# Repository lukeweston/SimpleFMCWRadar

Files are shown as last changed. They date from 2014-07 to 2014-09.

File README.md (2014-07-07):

This relatively compact, cheap, simple FMCW radar operates in the spectrum around 5.8-6.0 GHz and is aimed at lowering the barrier to entry for experiments with radar and general education around RF and microwave electronics. It is capable of speed measurement,
rangefinding and SAR imaging (with appropriate moving antennas or a moving vehicle.) It is potentially applicable to experiments with autonomous aircraft (or spacecraft) altitude-finding, SAR imaging/mapping or navigation as an alternative to (or in addition to)
other sensing techniques such as GPS, ultrasonics, LIDAR or barometry, without some of the limitations applicable to those technologies.

This is still an early prototype, a rough quick work that is still very much in progress and evolving as bits are designed and built and redesigned.

Frequency-modulated RF is generated by the HMC431 VCO, at about 5.8-6.0 GHz, amplified by a HMC476 MMIC gain block, and split in half by the Wilkinson divider. Half the RF output from the divider is amplified again and sent to the transmit antenna connector.
The local oscillator, from the other side of the splitter, is amplified again and applied to the LO port of the HMC219 double-balanced mixer. The reflected RF from the receive antenna comes in to the HMC717 6 GHz LNA where it is amplified, and the amplified output is
fed into the mixer.

A couple of pi attenuators are used, after the VCO, before the mixer LO port and after the mixer's IF output, to "tune" optimal mixer LO level and overall performance. Although I haven't fixed certain values for these attenuators yet, space for them is left on
the board.

IF filtering, amplification and signal processing, along with generation of the 0-10V modulation signal for the VCO, are done on a separate board.

Source files - EDA/CAD information: These are CadSoft EAGLE files. See www.cadsoftusa.com/ for download and licensing information. The "free as in beer" "light" Eagle license is perfectly capable of opening and editing these files - the boards are only two-layer and
are relatively small. A PDF schematic is provided along with industry-standard fabrication-ready RS274X (Gerber) files.

License information: Open Hardware as per the CERN Open Hardware License; please see license.txt

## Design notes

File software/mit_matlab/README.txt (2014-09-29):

NOTE:
These MATLAB files are, at this stage, simply "forked" from the public files provided by Greg Charvat and his MIT/Lincoln Lab group.

You may find the original MATLAB signal-processing scripts and other documentation here:

http://ocw.mit.edu/resources/res-ll-003-build-a-small-radar-system-capable-of-sensing-range-doppler-and-synthetic-aperture-radar-imaging-january-iap-2011/projects/

All credit, ownership, IP rights, license terms and so forth belong to Greg Charvat - not me!

I am currently working on making some tweaks and changes to acheive the following goals:

- Adaptations to suit the centre frequency, sweep bandwidth and modulation rate of my radar electronics

- Avoid the use of expensive commercial software like MATLAB, and adapt the code for signal processing of the audio samples such that
the same results can be had without proprietary software.

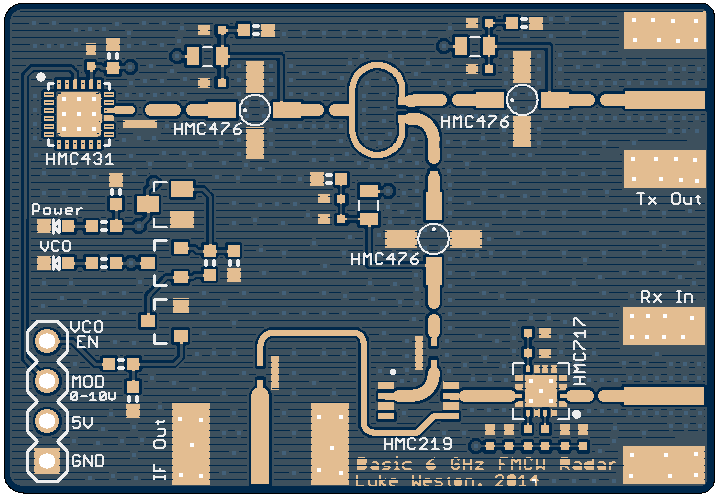
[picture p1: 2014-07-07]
photos/RFboard-preview.png

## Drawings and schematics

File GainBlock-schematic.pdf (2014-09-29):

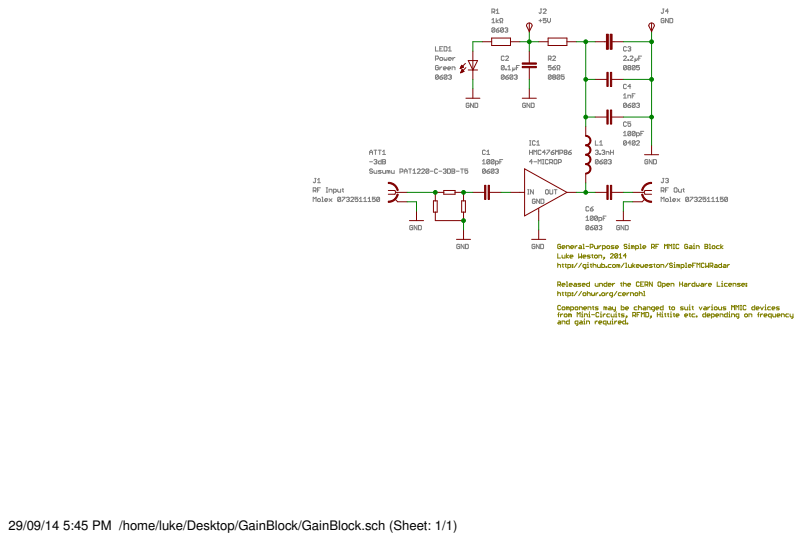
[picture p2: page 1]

29/09/14 5:45 PM /home/luke/Desktop/GainBlock/GainBlock.sch (Sheet: 1/1)

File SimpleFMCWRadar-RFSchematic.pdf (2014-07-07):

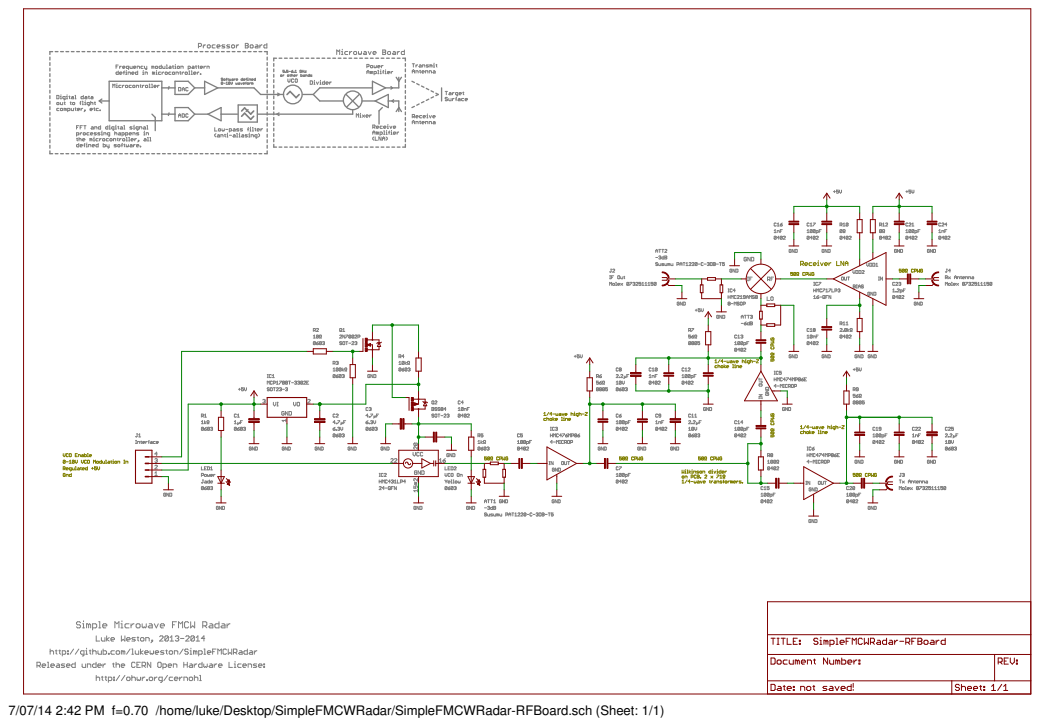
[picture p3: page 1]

7/07/14 2:42 PM f=0.70 /home/luke/Desktop/SimpleFMCWRadar/SimpleFMCWRadar-RFBoard.sch (Sheet: 1/1)

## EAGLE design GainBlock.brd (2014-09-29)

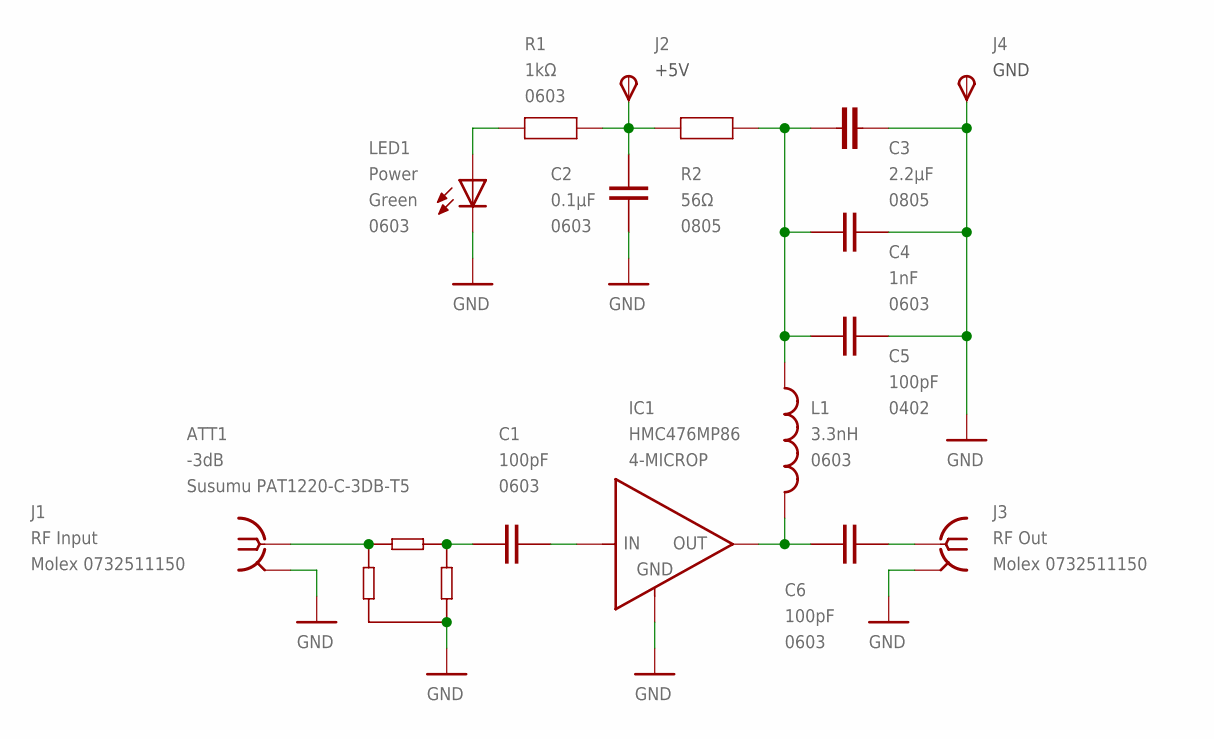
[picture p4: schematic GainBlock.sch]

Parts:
ATT1: -3dB; PAT1220
C1, C6: 100pF; 0603
C2: 0.1µF; 0603
C3: 2.2µF; 0805; VOLTAGE 10V
C4: 1nF; 0603
C5: 100pF; 0402
IC1: HMC476MP86; WW107
J1: RF Input; J502-ND-142-0701-881/886; MPN 142-0701-881
J2, J4: TPSPAD1-13; P1-13
J3: RF Out; J502-ND-142-0701-881/886; MPN 142-0701-881
L1: 3.3nH; 0603
LED1: Power; LED-0603
R1: 1kΩ; 0603
R2: 56Ω; 0805

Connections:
GND: ATT1.3, C2.2, C3.1, C4.2, C5.2, IC1.2 (GND), IC1.4 (GND), J1.G@1 (GND), J1.G@2 (GND), J1.G@3 (GND), J1.G@4 (GND), J3.G@1 (GND), J3.G@2 (GND), J3.G@3 (GND), J3.G@4 (GND), J4.TP, LED1.C
unnamed: ATT1.1, J1.1
unnamed: ATT1.2, C1.1
unnamed: LED1.A, R1.1
unnamed: C6.2, J3.1
unnamed: C1.2, IC1.1 (IN)
unnamed: C6.1, IC1.3 (OUT), L1.2
unnamed: C3.2, C4.1, C5.1, L1.1, R2.1
unnamed: C2.1, J2.TP, R1.2, R2.2

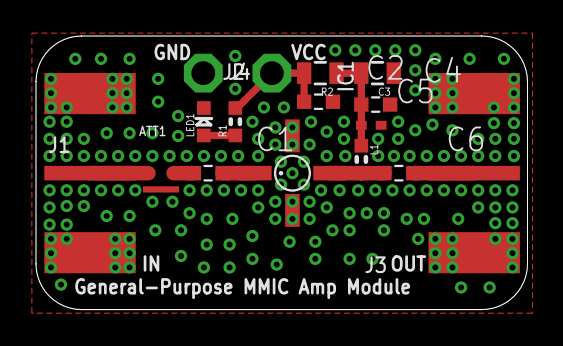
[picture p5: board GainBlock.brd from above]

Board: 2 copper layers, 27.3 x 15.2 mm, 16 parts (0 on the bottom side), 9 nets.

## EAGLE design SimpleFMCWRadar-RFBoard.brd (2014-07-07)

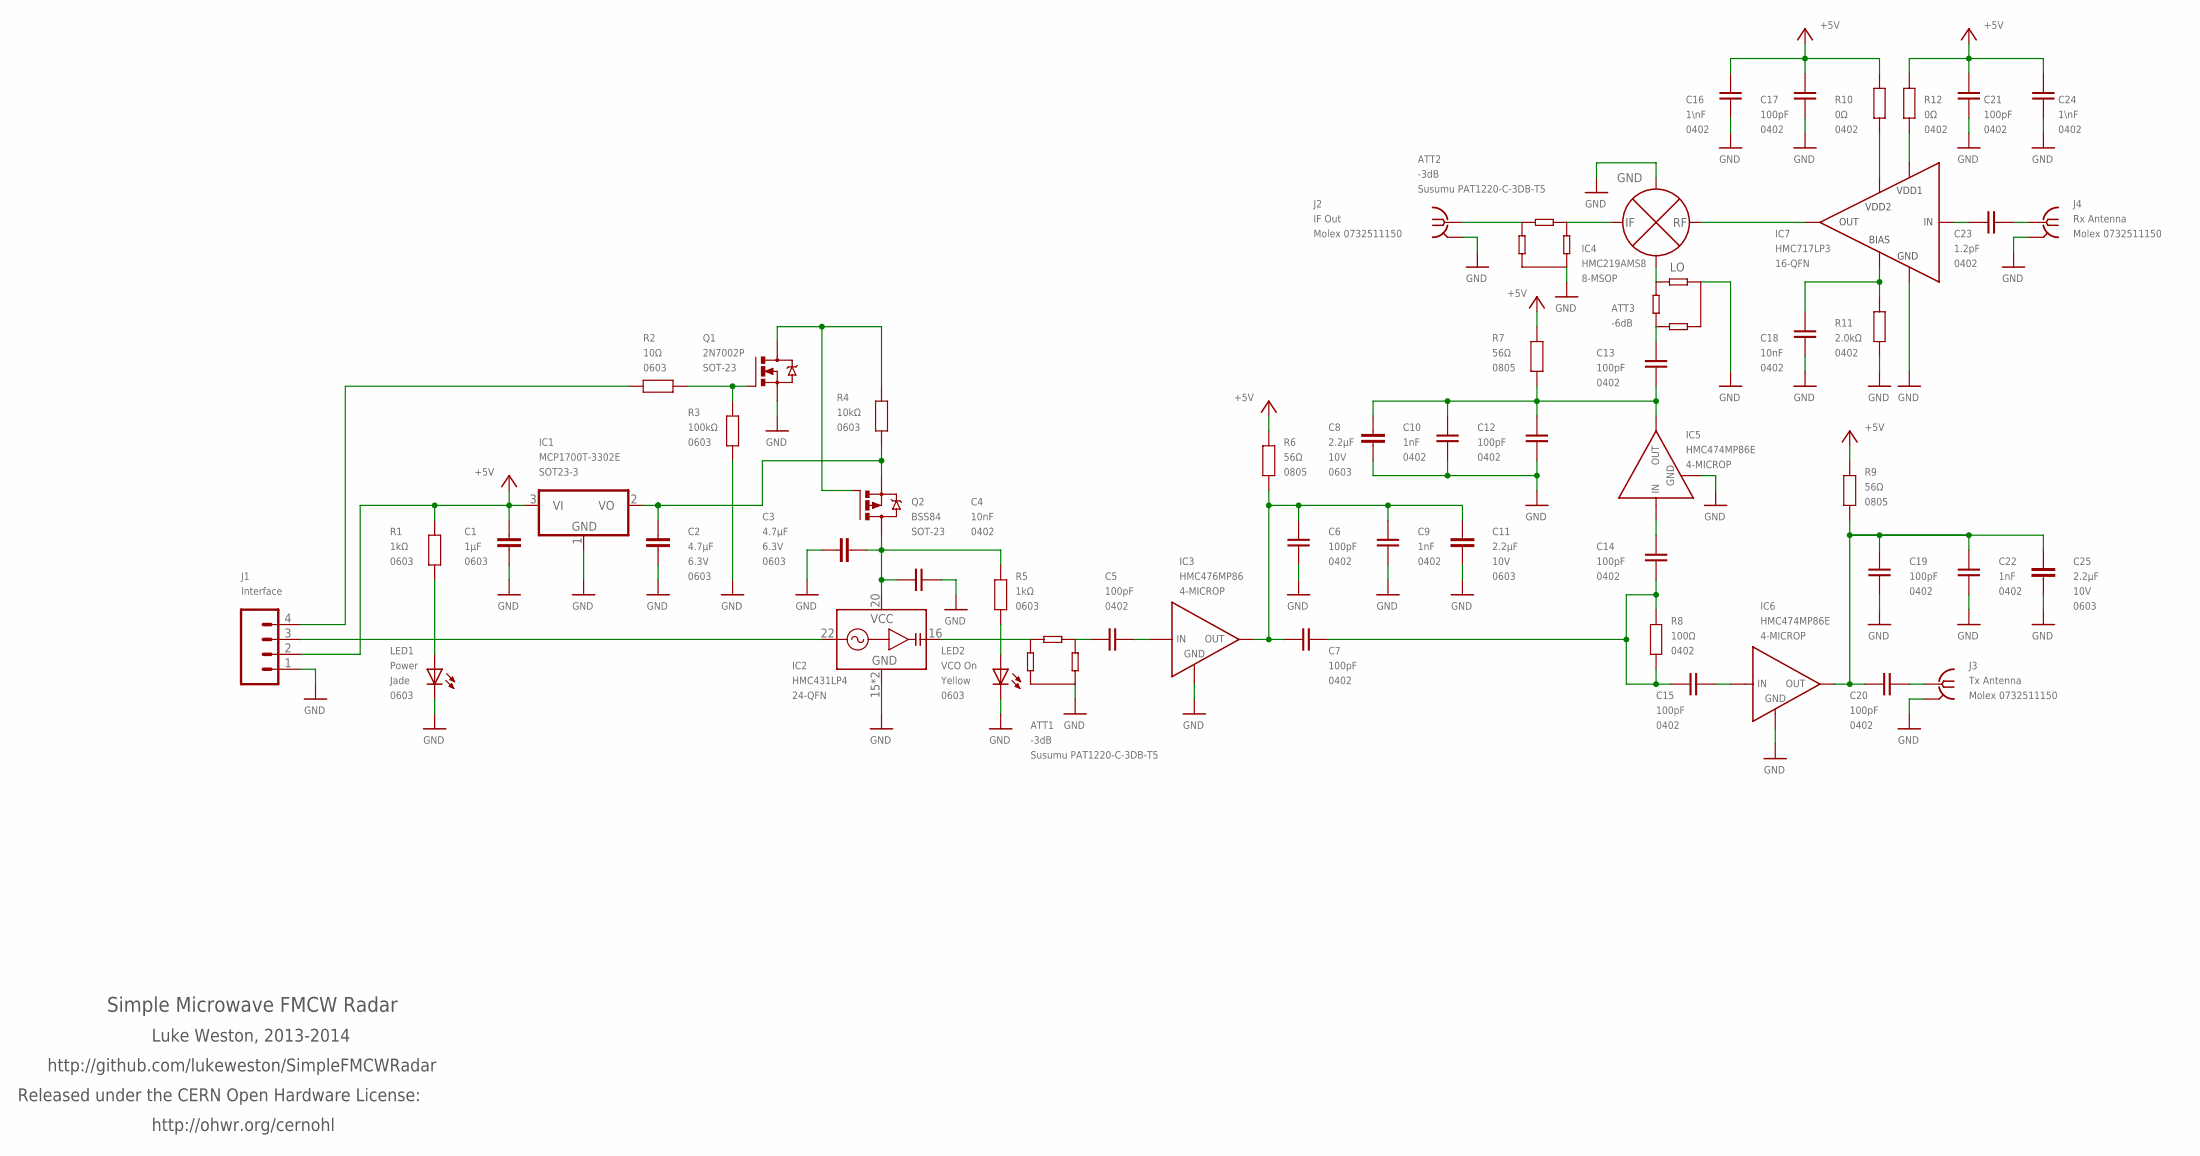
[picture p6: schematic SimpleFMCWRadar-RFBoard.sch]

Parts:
ATT1, ATT2: -3dB; PAT1220
ATT3: -6dB; PAT1220
C1: 1µF; 0603
C2, C3: 4.7µF; 0603; VOLTAGE 6.3V
C4, C18: 10nF; 0402
C5, C6, C7, C12, C13, C14, C15, C17, C19, C20, C21: 100pF; 0402
C8, C11, C25: 2.2µF; 0603; VOLTAGE 10V
C9, C10, C22: 1nF; 0402
C16, C24: 1\nF; 0402
C23: 1.2pF; 0402
IC1: MCP1700T-3302E; SOT23
IC2: HMC431LP4; QFN24
IC3: HMC476MP86; WW107
IC4: HMC219AMS8; 8-MSOP
IC5, IC6: HMC474MP86E; WW107
IC7: HMC717LP3; 16-QFN
J1: Interface; 1X04
J2: IF Out; J502-ND-142-0701-881/886; MPN 142-0701-881
J3: Tx Antenna; J502-ND-142-0701-881/886
J4: Rx Antenna; J502-ND-142-0701-881/886
LED1: Power; LED-0603
LED2: VCO On; LED-0603
Q1: 2N7002P; SOT23-3
Q2: BSS84; SOT23-3
R1, R5: 1kΩ; 0603
R2: 10Ω; 0603
R3: 100kΩ; 0603
R4: 10kΩ; 0603
R6, R7, R9: 56Ω; 0805
R8: 100Ω; 0402
R10, R12: 0Ω; 0402
R11: 2.0kΩ; 0402

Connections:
+5V: C1.2, C16.2, C17.2, C21.2, C24.2, IC1.3 (VI), J1.2, R1.2, R6.2, R7.1, R9.1, R10.2, R12.2
GND: ATT1.3, ATT2.3, ATT3.3, C1.1, C2.2, C3.2, C4.2, C6.1, C8.1, C9.1, C10.1, C11.1, C12.1, C16.1, C17.1, C18.1, C19.2, C21.1, C22.2, C24.1, C25.1, IC1.1 (GND), IC2.15 (GND), IC2.EXP (GND), IC3.2 (GND), IC3.4 (GND), IC4.1 (GND), IC4.3 (GND), IC4.6 (GND), IC4.8 (GND), IC5.2 (GND), IC5.4 (GND), IC6.2 (GND), IC6.4 (GND), IC7.P$1 (GND), IC7.P$3 (GND), IC7.P$4 (GND), IC7.P$5 (GND), IC7.P$6 (GND), IC7.P$7 (GND), IC7.P$9 (GND), IC7.P$10 (GND), IC7.P$12 (GND), IC7.P$14 (GND), IC7.P$16 (GND), IC7.PAD (GND), J1.1, J2.G@1 (GND), J2.G@2 (GND), J2.G@3 (GND), J2.G@4 (GND), J3.G@1 (GND), J3.G@2 (GND), J3.G@3 (GND), J3.G@4 (GND), J4.G@1 (GND), J4.G@2 (GND), J4.G@3 (GND), J4.G@4 (GND), LED1.C, LED2.C, Q1.2 (S), R3.1, R11.1
unnamed: C5.2, IC3.1 (IN)
unnamed: C6.2, C7.1, C9.2, C11.2, IC3.3 (OUT), R6.1
unnamed: ATT1.2, C5.1
unnamed: ATT1.1, IC2.16 (RFOUT)
unnamed: IC2.22 (VTUNE), J1.3
unnamed: C15.1, IC6.1 (IN)
unnamed: C7.2, C14.1, C15.2, R8.1, R8.2
unnamed: C20.1, J3.1
unnamed: ATT3.2, IC4.2 (LO)
unnamed: Q1.1 (G), R2.1, R3.2
unnamed: ATT2.2, IC4.5 (IF)
unnamed: C23.2, IC7.P$2 (IN)
unnamed: C23.1, J4.1
unnamed: IC4.7 (RF), IC7.P$11 (OUT)
unnamed: C18.2, IC7.P$8 (BIAS), R11.2
unnamed: IC7.P$13 (VDD2), R10.1
unnamed: IC7.P$15 (VDD1), R12.1
unnamed: LED1.A, R1.1
unnamed: ATT3.1, C13.2
unnamed: C3.1, C4.1, IC2.20 (VCC), Q2.3 (D), R5.2
unnamed: C2.1, IC1.2 (VO), Q2.2 (S), R4.1
unnamed: Q1.3 (D), Q2.1 (G), R4.2
unnamed: J1.4, R2.2
unnamed: C19.1, C20.2, C22.1, C25.2, IC6.3 (OUT), R9.2
unnamed: LED2.A, R5.1
unnamed: C8.2, C10.2, C12.2, C13.1, IC5.3 (OUT), R7.2
unnamed: C14.2, IC5.1 (IN)
unnamed: ATT2.1, J2.1

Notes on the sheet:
Simple Microwave FMCW Radar
Luke Weston, 2013-2014
http://github.com/lukeweston/SimpleFMCWRadar
Released under the CERN Open Hardware License:
http://ohwr.org/cernohl

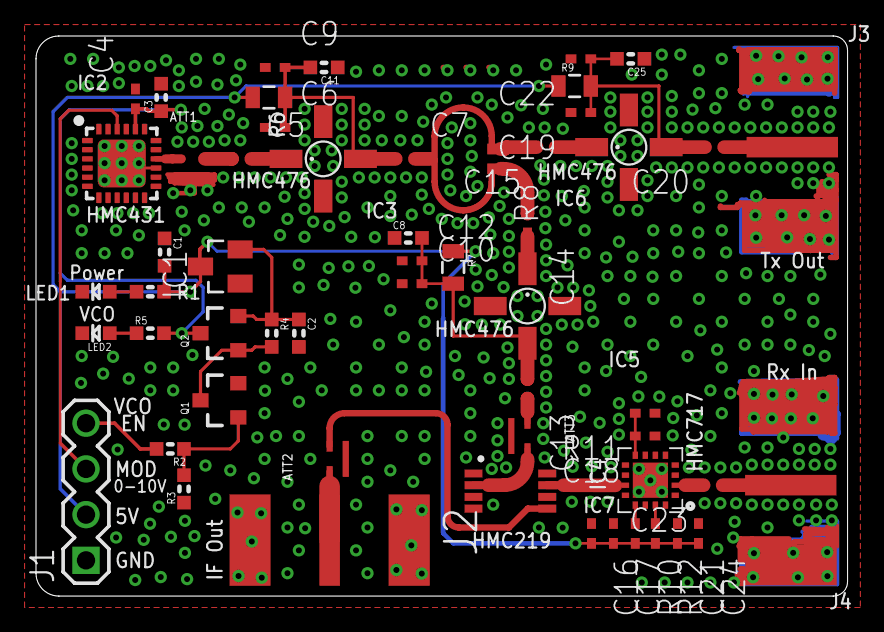
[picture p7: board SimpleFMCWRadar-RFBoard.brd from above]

Board: 2 copper layers, 45.1 x 31.1 mm, 55 parts (0 on the bottom side), 30 nets.

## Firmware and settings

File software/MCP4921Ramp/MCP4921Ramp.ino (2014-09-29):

// Basic demo of flexible, software-controlled ramp waveform synthesis (triangle wave in this case).
// Using an Arduino and Microchip MCP4921 12-bit SPI DAC.
// Ramp magnitude goes from 0 to VRef (single-ended), Vref is 5V in this case.

// Luke Weston, 2014
// License: Creative Commons attribution-noncommercial-sharealike - http://creativecommons.org/licenses/by-nc-sa/4.0/
// This license only applies to this file - other files (eg. my CERN OHL-licensed hardware files) may use different licence - see docs.

#define CS 10
#include "SPI.h"
word output = 0;
byte data = 0;

void setup()
{
  pinMode(CS, OUTPUT);
  SPI.begin();
  SPI.setBitOrder(MSBFIRST);
}
 
void loop()
{
  for (int i=0; i<=4095; i++)
  {
    outputValue = i;
    digitalWrite(CS, LOW);
    data = highByte(value);
    data = 0b00001111 & data;
    data = 0b00110000 | data;
    SPI.transfer(data);
    data = lowByte(value);
    SPI.transfer(data);
    digitalWrite(CS, HIGH);
  }
  delay(25);
  
  for (int i=4095; i>=0; --i)
  {
    outputValue = i;
    digitalWrite(CS, LOW);
    data = highByte(value);
    data = 0b00001111 & data;
    data = 0b00110000 | data;
    SPI.transfer(data);
    data = lowByte(value);
    SPI.transfer(data);
    digitalWrite(CS, HIGH);
  }
}

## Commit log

2014-07-07 added schematic
2014-07-07 added current RF board
    [SimpleFMCWRadar-RFBoard.brd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]
2014-09-29 added gain block breakout module
    [GainBlock.brd, GainBlock.sch]
